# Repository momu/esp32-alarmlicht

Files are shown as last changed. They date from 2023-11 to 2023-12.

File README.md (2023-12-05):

# ESP32 Alarmlicht

[ESPHome](https://esphome.io/) basierte, automatisierte Alarmauslösung über einen `http` request bei Alarmierung eines Melders in einer `LGRA` Ladestation.

Um automatisiert einen Alarm per `http` request (z.B. über [DIVERA 24/7](https://www.divera247.com)) auszulösen, wird der Relaiskontakt des Ladegeräts `Swissphone LGRA Expert` ausgewertet.

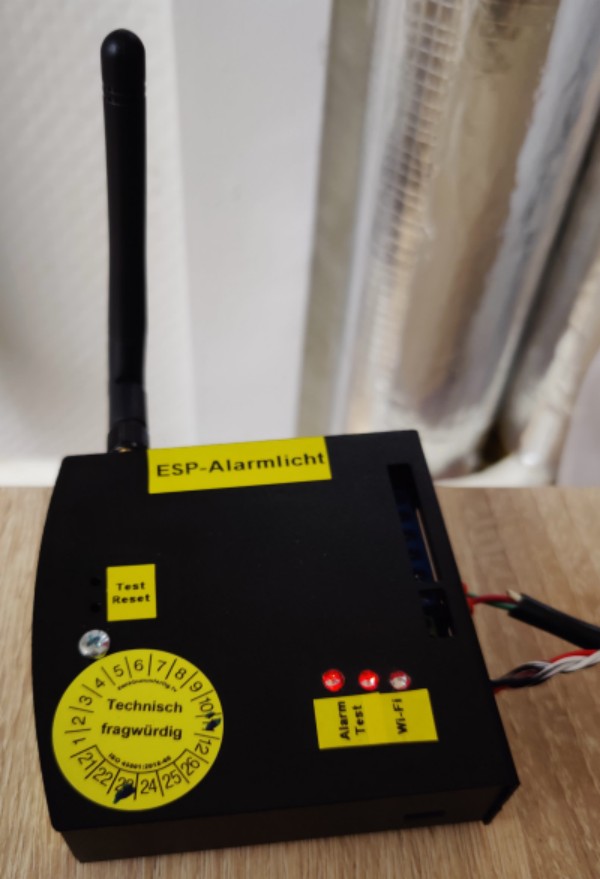
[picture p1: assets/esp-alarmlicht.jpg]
esp-alarmlicht nur echt mit loet.bar sticker


## Blockdiagramm

block diagram

Das `esp32-alarmlicht` wertet zwei `GPIO` Eingänge aus. `GPIO16` wird über ein Relais einer Funkfernbedienung angesteuert. Wird dieses Relais geschlossen, soll über ein Relais das Alarmlicht angesteuert werden.
`GPIO18` wird über das Relais im Ladegerät des Melders (DME) gesteuert. Wird das Relais geschlossen, soll das Alarmlicht angesteuert werden und ein `http` request ausgelöst werden.

## Status LEDs

Das `esp32-alarmlicht` verfügt über drei Status LEDs:

1. Auslösung des DME oder der Funkfernbedienung
1. Drücken des Testknopfes `BUT1`
1. Wi-Fi Verbindung (kurzes Blinken alle `3 s`)

## Hardware

Basis des `esp32-alarmlicht` ist ein [ESP32-EVB-EA-IND](https://www.olimex.com/Products/IoT/ESP32/ESP32-EVB) Board mit einem `ESP32-WROOM-32UE` Modul.

Die Statusanzeige erfolgt über drei LEDs, die mit `3k` Widerständen versehen sind.

Die beiden potenzialfreien Kontakte des Ladegerätes und des Funklichtes sind mit einem Pull-up Widerstand versehen und werden bei der Auslösung auf `GND` gezogen.

Die Stromversorgung des `ESP32-EVB-EA-IND` erfolgt über die Pins `2` und `4` des LGRA. Diese sind mit den Pads des unbestückten Steckers `PWR2` des Olimex-Boards verbunden.

Für eine korrekte Funktion muss im [`LGRA` eine Lötbrücke entfernt](#ladegerät-swissphone-lgra-expert) werden.

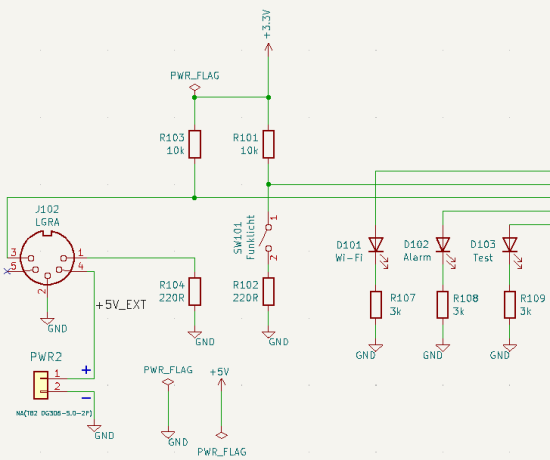
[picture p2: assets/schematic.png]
schematic


Vollständiges Schematic als `KiCad` Projekt oder als [PDF](hardware/esp32-alarmlicht.pdf) in [hardware/](hardware/).

### Bill Of Materials

* [ESP32-EVB-EA-IND](https://www.olimex.com/Products/IoT/ESP32/ESP32-EVB)
* [BOX-ESP32-EVB-EA](https://www.olimex.com/Products/IoT/ESP32/BOX-ESP32-EVB-EA)
* 3x LED
* Widerstände
  * 2x `220R`
  * 3x `3k`
  * 2x `10k`
* DIN Stecker 5-polig male
* [Plakette »Technisch fragwürdig«](https://loet.bar/products/plakette-fragwuerdig-sticker)

## Software

Die Software basiert auf [ESPHome](https://esphome.io). Das Konfigurationsfile ist [alarmlicht.yaml](alarmlicht.yaml).
Je nach Konfiguration wird bei Alarm- oder Testauslösung ein API-Request an `DIVERA` und [ntfy](https://ntfy.sh/) gesendet. Das Verhalten wird über die Variablen `global_send_*` gesteuert. Eine Testauslösung erfolgt über `BUT1` des `ESP32-EVB-EA-IND`.

Das File `secrets.yaml` enthält folgende Angaben:

* Wi-Fi Konfigurations- und Zugangsdaten
* `ntfy` URL
* `DIVERA` API Key

Beispieldaten befinden sich in  [secrets-example.yaml](secrets-example.yaml). Diese Datei muss in `secrets.yaml` umbenannt werden und mit echten Daten gefüllt werden.

[alarmlicht.yaml](alarmlicht.yaml) bindet folgende Dateien ein:

* [on-but1-press.yaml](on-but1-press.yaml): `BUT1` wird betätigt
* [on-message-receive.yaml](on-message-receive.yaml): `GPI016` oder `GPIO18` werden auf `GND` gezogen
* [send-alerts.yaml](send-alerts.yaml): Auslösen von `http` requests durch das Einbinden von
  * [http-request-divera.yaml](http-request-divera.yaml): Auslösen eines `DIVERA` `http` requests
  * [http-request-ntfy.yaml](http-request-ntfy.yaml): Auslösen eines `ntfy` `http` requests

Wird ein Alarm ausgelöst während keine Wi-Fi Verbindung besteht, wird der Alarm gespeichert und anschließend bei bestehender Wi-Fi Verbindung ausgelöst. Das Speichern geschieht über die globale Variable `global_alert_pending`.

Da der `http` request nicht immer erfolgreich ist, wird der Statuscode ausgewertet. Ist er nicht `200` und `429` wird mehrmals versucht, den `http` request zu senden. Das Verhalten und die maximale Anzahl der Versuche wird über die globalen Variablen `global_divera_http_request_*` gesteuert.

### Setup

```bash
python -m venv .venv
source .venv/bin/activate
pip install -r requirements.txt
esphome wizard alarmlicht.yaml
esphome run alarmlicht.yaml
```

### Building, Running, Logs

> The `esphome run <CONFIG>` command is the most common command for ESPHome. It
>
> * Validates the configuration
> * Compiles a firmware
> * Uploads the firmware (over OTA or USB)
> * Starts the log view

```bash
esphome run alarmlicht.yaml
```

> The `esphome logs <CONFIG>` command validates the configuration and shows all logs.

```bash
esphome logs alarmlicht.yaml
```

## Ladegerät Swissphone LGRA Expert

Das Ladegerät verfügt über einen fünfpoligen DIN-Stecker (female) mit folgender Belegung:

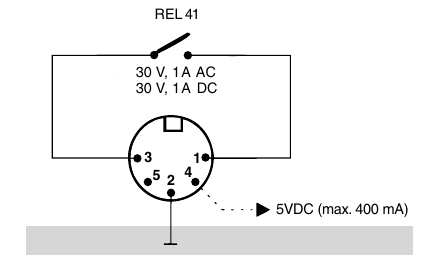
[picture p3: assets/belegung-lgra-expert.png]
pinout lgra expert

Quelle: [Ladegerät (A)LGRA Expert (PDF)](assets/datenblatt-lgra-expert.pdf)

Pin `4` ist mit der Stromversorgung des Netzteils verbunden (`+5V`), Pin `2` ist `GND`, Pins `1` und `3` werden potentialfrei durch ein Relais geschaltet.

### Relaiskonfiguration/Lötbrücke

Im Auslieferungszustand wird der Relaiskontakt geschlossen wenn der DME eine Meldung empfängt. Der Kontakt wird wieder geöffnet, wenn alle Meldungen quittiert wurden.

Über eine Lötbrücke wird das Verhalten des Relais konfiguriert. Wird diese Lötbrücke entfernt, so wird das Relais bei jedem Meldungseingang für ca. `10 s` geschlossen, unabhängig vom Quittieren vorheriger Meldungen.

Für die Verwendung des Ladegerätes mit dem `esp32-alarmlicht` muss die Lötbrücke entfernt werden.

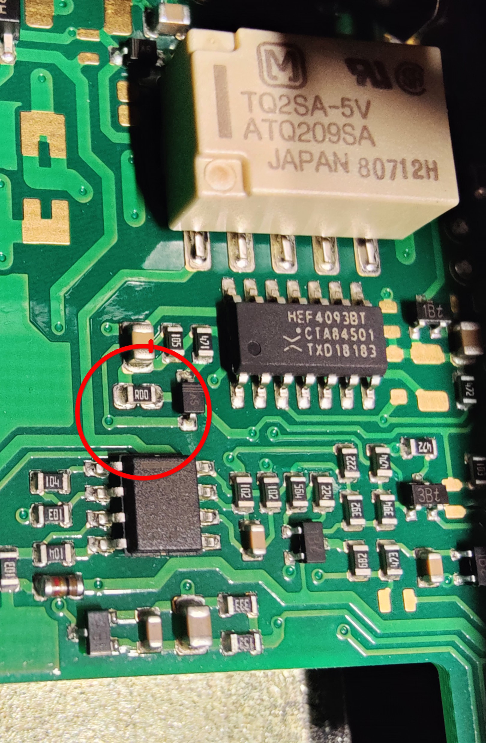
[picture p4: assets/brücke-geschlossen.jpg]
solder jumper closed lgra expert


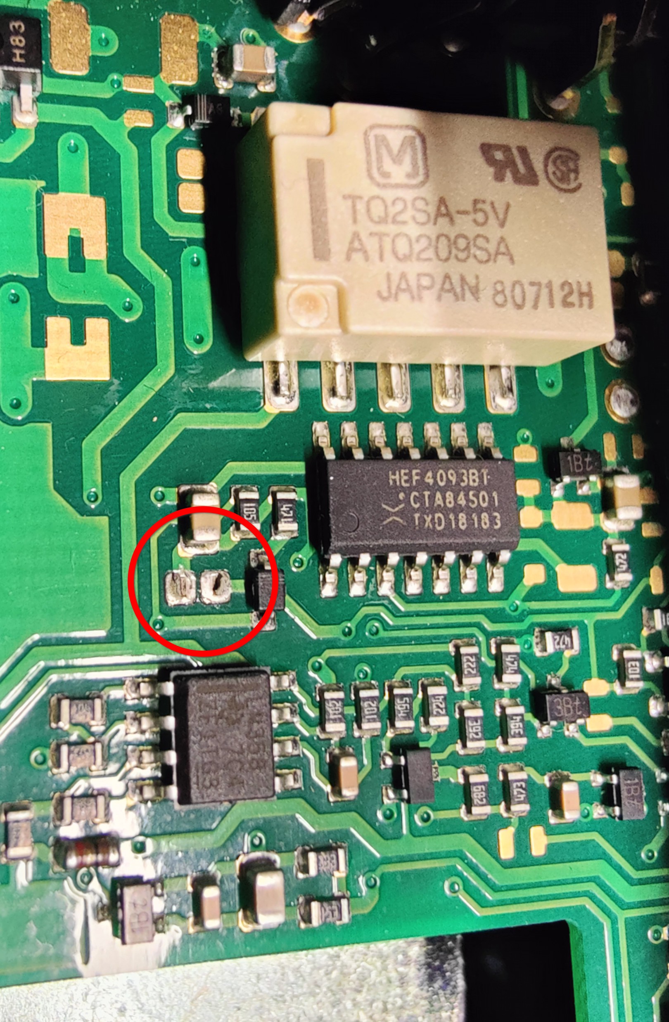
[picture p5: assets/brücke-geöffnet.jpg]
solder jumper open lgra expert


## Ressourcen

* https://esphome.io
* https://docs.ntfy.sh
* https://www.kicad.org
* https://api.divera247.com
* [DIVERA Web-Schnittstelle (API Dokumentation)](https://help.divera247.com/pages/viewpage.action?pageId=19563127)
* [Olimex ESP32-EVB](https://www.olimex.com/Products/IoT/ESP32/ESP32-EVB/open-source-hardware)
* https://github.com/OLIMEX/ESP32-EVB
* [ESP32-WROOM-32E & ESP32-WROOM-32UE Datasheet](https://www.espressif.com/en/content/esp32-wroom-32e-esp32-wroom-32ue-datahseet)
  
## Bugs, Questions And Contributions

Please use the [projects issue tracker](https://github.com/momu/esp32-alarmlicht/issues) or create a [GitHub pull request](https://github.com/momu/esp32-alarmlicht/pulls).

## Lizenz

<p xmlns:cc="http://creativecommons.org/ns#" xmlns:dct="http://purl.org/dc/terms/"><a property="dct:title" rel="cc:attributionURL" href="https://github.com/momu/esp32-alarmlicht/">ESP32-Alarmlicht</a> is licensed under <a href="http://creativecommons.org/licenses/by-nc-sa/4.0/?ref=chooser-v1" target="_blank" rel="license noopener noreferrer" style="display:inline-block;">CC BY-NC-SA 4.0</a></p>

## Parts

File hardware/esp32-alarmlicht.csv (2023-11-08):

Source: | ~/github/esp32-remote-alarmlicht/hardware/esp32-alarmlicht.kicad_sch
Date: | Di 07 Nov 2023 19:47:34 CET
Tool: | Eeschema 7.0.8
Generator: | /usr/share/kicad/plugins/bom_csv_grouped_by_value.py
Component Count: | 14
Collated Components:
Item | Qty | Reference(s) | Value | LibPart | Footprint | Datasheet | DNP | Fieldname 1 | Fieldname2 | Fieldname3
1 | 1 | D101 | Wi-Fi | Device:LED |  | ~
2 | 1 | D102 | Alarm | Device:LED |  | ~
3 | 1 | D103 | Test | Device:LED |  | ~
4 | 1 | EXT101 | NA(HN2x20) | Connector_Generic:Conn_02x20_Odd_Even | OLIMEX_Connectors-FP:HN2x20 | ~ |  | Value 1 | Value2 | Value3
5 | 1 | J102 | LGRA | Connector:DIN-5_180degree |  | http://www.mouser.com/ds/2/18/40_c091_abd_e-75918.pdf
6 | 1 | PWR101 | NA(TB2 DG306-5.0-2P) | Connector_Generic:Conn_01x02 | OLIMEX_Connectors-FP:TB2-DG306-5.0_2P | ~ |  | Value 1 | Value2 | Value3
7 | 2 | R101, R103 | 10k | Device:R |  | ~
8 | 2 | R102, R104 | 220R | Device:R |  | ~
9 | 3 | R107, R108, R109 | 3k | Device:R |  | ~
10 | 1 | SW101 | Funklicht | Switch:SW_SPST |  | ~

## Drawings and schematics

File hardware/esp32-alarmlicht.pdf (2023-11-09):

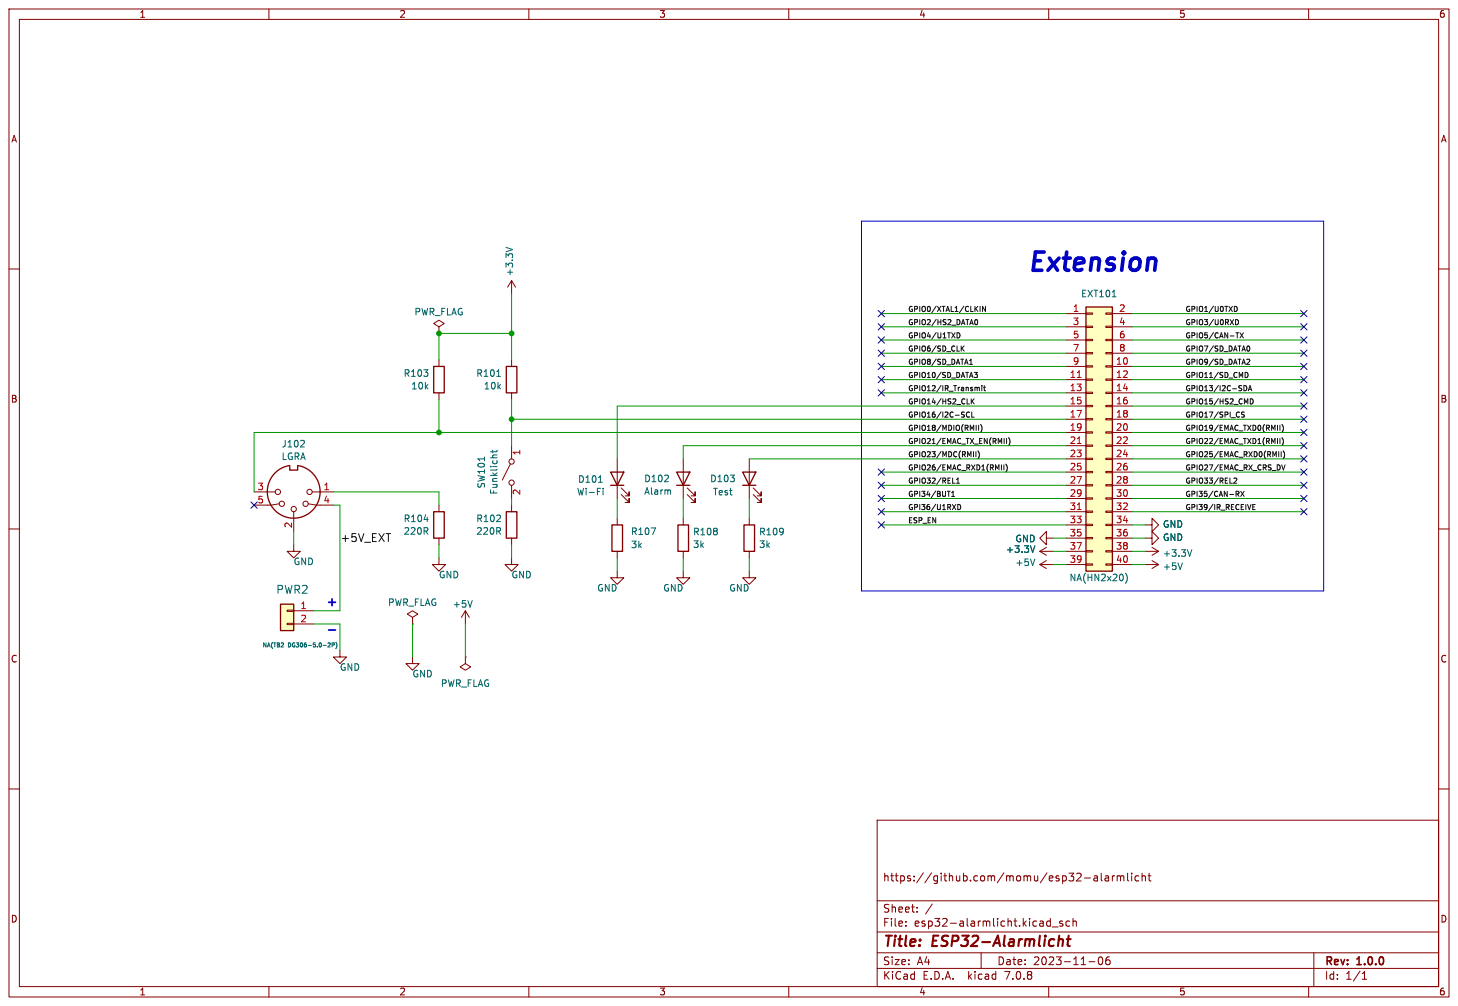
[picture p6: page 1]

Id: 1/1 Title: ESP32-Alarmlicht File: esp32-alarmlicht.kicad_sch Sheet: / https://github.com/momu/esp32-alarmlicht PWR_FLAG

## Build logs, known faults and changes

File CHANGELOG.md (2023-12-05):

# Changelog

All notable changes to this project will be documented in this file.

## [1.2.0](https://github.com/momu/esp32-alarmlicht/compare/v1.1.0...v1.2.0) - 2023-12-05

* add retry logic when http request fails #7
* include send-test-alerts.yaml into send-alerts.yaml
* add some global variables for http request retries and alert type to be sent

## [1.1.0](https://github.com/momu/esp32-alarmlicht/compare/v1.0.1...v1.1.0) - 2023-11-25

* finalize documentation
* when there is no wifi connection, remember pending alerts (#5)
* code modularisation, improve reusability 

## [1.0.1](https://github.com/momu/esp32-alarmlicht/compare/v1.0.0...v1.0.1) - 2023-11-09

* disable power saving mode for solving #3

## [1.0.0](https://github.com/momu/esp32-alarmlicht/releases/tag/v1.0.0) - 2023-11-03

* initial release

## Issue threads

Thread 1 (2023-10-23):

Build this thing and document it

momu, 2023-10-23:
## Documentation

* [x]  BOM
* [x] connection scheme (fritzing?)
* [x] esphome setup

## Code

* [x] two wifis
* [x] secrets in `.gitignore`
* [x] when button is pushed, a test alarm on divera should be triggered
* [x] when relays is closed on docking station, trigger two different http requests

## Hardware

* [x] pullup (`10 k`) with `220R` protection

Closed 2023-11-09.

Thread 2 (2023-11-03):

[bug] software crashes when making http requests

momu, 2023-11-03:
When using the configuration as in 896cde274d4a6dda978874c5ccf0fc399cc1f738 an triggering a test alert using the testbutton, the devices crashes and reboots when sending an http request to http://ntfy.sh immediatly after sending a successful request to `Divera`.
Could be related to https://github.com/esphome/issues/issues/2853.

First workaround is to disable the `ntfy` request and set the timeout for the http component to `1 s`.

Log with `loglevel: DEBUG`
```
[20:57:10][C][mdns:116]:   Hostname: esp-alarmlicht
[20:57:10][C][http_request:014]: HTTP Request:
[20:57:10][C][http_request:015]:   Timeout: 5000ms
[20:57:10][C][http_request:016]:   User-Agent: esphome/esp-alarmlicht
[20:57:10][C][http_request:017]:   Follow Redirects: 1
[20:57:10][C][http_request:018]:   Redirect limit: 3
[20:57:28][D][binary_sensor:036]: 'BUT1': Sending state ON
[20:57:28][D][main:512]: Button BUT1 pressed
[20:57:28][D][binary_sensor:036]: 'BUT1': Sending state OFF
[20:57:28][D][main:016]: Sending Divera test alert.
[20:57:31][D][main:027]: Response status: 429, Duration: 2721 ms
[20:57:31][W][http_request:093]: HTTP Request failed; URL: https://www.divera247.com/api/alarm?accesskey=<redacted>; Code: 429; Duration: 2721 ms
[20:57:31][D][main:024]: Sending ntfy test alert.
[20:57:33]E (45555) task_wdt: Task watchdog got triggered. The following tasks did not reset the watchdog in time:
[20:57:33]E (45555) task_wdt:  - loopTask (CPU 1)
[20:57:33]E (45555) task_wdt: Tasks currently running:
[20:57:33]E (45555) task_wdt: CPU 0: IDLE
[20:57:33]E (45555) task_wdt: CPU 1: loopTask
[20:57:33]E (45555) task_wdt: Aborting.
[20:57:33]abort() was called at PC 0x400ea529 on core 0
[20:57:33]Backtrace:0x40083881:0x3ffbe9bc |<-CORRUPTED
WARNING Found stack trace! Trying to dhttps://github.com/esphome/issues/issues/2853ecode it
WARNING Decoded 0x40083881: panic_abort at /Users/ficeto/Desktop/ESP32/ESP32S2/esp-idf-public/components/esp_system/panic.c:402
[20:57:33]ELF file SHA256: 0000000000000000
[20:57:33]Rebooting...
[20:57:33]ets Jul 29 2019 12:21:46
[20:57:33]rst:0xc (SW_CPU_RESET),boot:0x1b (SPI_FAST_FLASH_BOOT)
[20:57:33]configsip: 0, SPIWP:0xee
[20:57:33]clk_drv:0x00,q_drv:0x00,d_drv:0x00,cs0_drv:0x00,hd_drv:0x00,wp_drv:0x00
[20:57:33]mode:DIO, clock div:2
[20:57:33]load:0x3fff0030,len:1184
[20:57:33]load:0x40078000,len:13132
[20:57:33]load:0x40080400,len:3036
[20:57:33]entry 0x400805e4
[20:57:33][I][logger:326]: Log initialized
[20:57:33][I][app:029]: Running through setup()...
[20:57:33][D][binary_sensor:034]: 'Funklicht': Sending initial state OFF
[20:57:33][D][binary_sensor:034]: 'BUT1': Sending initial state OFF
[20:57:33][D][binary_sensor:034]: 'DME Relais': Sending initial state OFF
```

Log with `loglevel: INFO`

```
[21:00:38][I][wifi:560]: WiFi Connected!
[21:00:38][I][app:062]: setup() finished successfully!
[21:00:38][I][app:102]: ESPHome version 2023.10.4 compiled on Nov  2 2023, 20:59:39
[21:00:58]E (39574) task_wdt: Task watchdog got triggered. The following tasks did not reset the watchdog in time:
[21:00:58]E (39574) task_wdt:  - loopTask (CPU 1)
[21:00:58]E (39574) task_wdt: Tasks currently running:
[21:00:58]E (39574) task_wdt: CPU 0: IDLE
[21:00:58]E (39574) task_wdt: CPU 1: IDLE
[21:00:58]E (39574) task_wdt: Aborting.
[21:00:58]abort() was called at PC 0x400e9aa1 on core 0
[21:00:58]Backtrace:0x40083881:0x3ffbe9bc |<-CORRUPTED
WARNING Found stack trace! Trying to decode it
WARNING Decoded 0x40083881: panic_abort at /Users/ficeto/Desktop/ESP32/ESP32S2/esp-idf-public/components/esp_system/panic.c:402
[21:00:58]ELF file SHA256: 0000000000000000
[21:00:58]
[21:00:58]Rebooting...
[21:00:58]ets Jul 29 2019 12:21:46
```

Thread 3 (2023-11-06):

[bug] frequent wifi disconnects every 30 mins

momu, 2023-11-06:
The wifi connection is pretty unstable, but predictable. It disconnects every 30 mins for 1-2 s.

## Logs

```
[16:51:58][W][wifi:138]: WiFi Connection lost... Reconnecting...
[16:51:58][W][wifi_esp32:458]: Event: Disconnected ssid='<SSID>' bssid=AA:BB:CC:DD:EE:FF reason='Unspecified'
[16:51:58][W][wifi_esp32:458]: Event: Disconnected ssid='<SSID>' bssid=AA:BB:CC:DD:EE:FF reason='Authentication Failed'
[16:51:58][W][wifi:607]: Connecting to WiFi network failed. Are the credentials wrong?
[16:52:09][I][wifi:487]: - '<SSID>' (AA:BB:CC:DD:EE:FF) ▂▄▆█
[16:52:09][I][wifi:277]: WiFi Connecting to '<SSID>'...
[16:52:09][W][wifi_esp32:458]: Event: Disconnected ssid='<SSID>' bssid=AA:BB:CC:DD:EE:FF reason='Association Leave'
[16:52:09][W][wifi:612]: WiFi Unknown connection status 0
[16:52:09][I][wifi:277]: WiFi Connecting to '<SSID>'...
[16:52:09][W][wifi_esp32:458]: Event: Disconnected ssid='<SSID>' bssid=AA:BB:CC:DD:EE:FF reason='Association Failed'
[16:52:09][W][wifi_esp32:458]: Event: Disconnected ssid='<SSID>' bssid=AA:BB:CC:DD:EE:FF reason='Association Failed'
[16:52:09][W][wifi:591]: Error while connecting to network.
[16:52:09][W][wifi:627]: Restarting WiFi adapter...
[16:52:09][W][component:214]: Component wifi took a long time for an operation (0.11 s).
[16:52:09][W][component:215]: Components should block for at most 20-30ms.
[16:52:21][I][wifi:487]: - '<SSID>' (AA:BB:CC:DD:EE:FF) ▂▄▆█
[16:52:21][I][wifi:277]: WiFi Connecting to '<SSID>'...
[16:52:22][I][wifi:560]: WiFi Connected!
[16:57:40][I][main:578]: Light switched on by remote control.
[16:59:18][I][main:578]: Light switched on by remote control.
[17:22:25][W][wifi_esp32:458]: Event: Disconnected ssid='<SSID>' bssid=AA:BB:CC:DD:EE:FF reason='Unspecified'
[17:22:25][W][wifi:138]: WiFi Connection lost... Reconnecting...
[17:22:25][I][wifi:277]: WiFi Connecting to '<SSID>'...
[17:22:26][I][wifi:560]: WiFi Connected!
```

## Ping

```
243 packets transmitted, 240 received, 1.23457% packet loss, time 242295ms
rtt min/avg/max/mdev = 75.584/91.944/189.828/25.980 ms
```

```
138 packets transmitted, 136 received, 1.44928% packet loss, time 137218ms
rtt min/avg/max/mdev = 78.068/120.949/207.613/25.195 ms
```
## To Do

* [ ] put logs here
* [ ] check connectivity/link quality by pinging the `esp`
* [x] set power saving mode (https://esphome.io/components/wifi.html#power-save-mode) to `none` according to https://community.home-assistant.io/t/esp32-disconnects/370258/9 -> did not solve it
* [ ] add some magic to catch alerts during wifi disconnects and process them once wifi is back

momu, 2023-11-08:
`power_save_mode: none` did not solve it

Closed 2024-05-14.

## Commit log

2023-10-26 led configured as light and initially off
2023-10-26 leds as outputs initially off
2023-10-28 Add more outputs, inputs and wifi indicator
    * two more LEDs added as output
    * two inputs configured
    * relay 1 as output (activated when BUT1 is pressed)
    * blinking wifi indicator
2023-11-07 wip: add schematic
    [esp32-alarmlicht.kicad_pcb, esp32-alarmlicht.kicad_sch]
2023-11-08 wip: readme; schematics done
    [esp32-alarmlicht.kicad_sch]
2023-11-08 wip: readme; bom, schematic export
    [esp32-alarmlicht.csv]
2023-11-08 disable power saving, readme
2023-11-09 finalize documentation, add changelog, fix typos
    [esp32-alarmlicht.kicad_sch]
2023-11-10 add sticker to BOM
